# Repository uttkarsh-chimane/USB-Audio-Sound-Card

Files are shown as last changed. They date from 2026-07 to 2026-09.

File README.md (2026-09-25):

<h1 align="center">⚡ PCM2706 USB Audio Sound Card</h1>

<p align="center">
  
  
  
  
  
</p>

---

## ⚙️ What I Built

A compact USB-powered stereo audio sound card designed around the Texas Instruments PCM2706C USB Audio Codec. The device converts USB digital audio streams into analog stereo output and provides a simple plug-and-play audio interface for computers supporting the USB Audio Class standard.

---

## 🚀 Overview

This project implements a USB audio playback device using the PCM2706C USB audio codec. The design integrates USB communication, clock generation, analog audio filtering, and stereo output circuitry on a compact PCB developed in KiCad.

The board is powered directly from the USB port and outputs analog audio through a 3.5 mm audio jack.

---

## 📷 Project Gallery

🧩 **3D PCB Render**

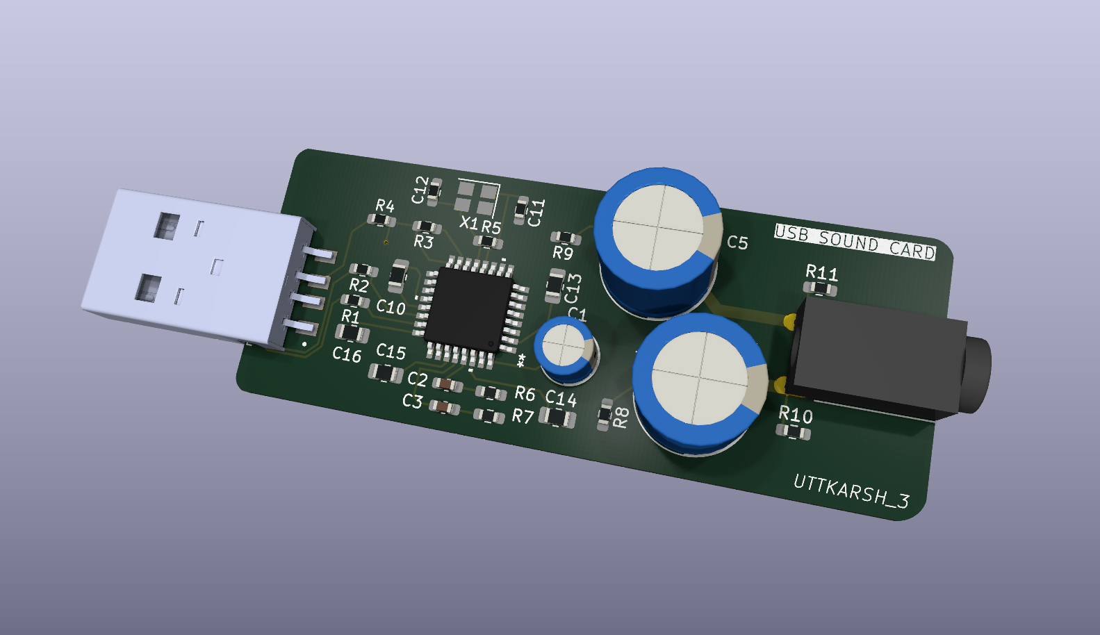
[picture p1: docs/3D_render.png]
3D PCB


🔌 **PCB Layout**

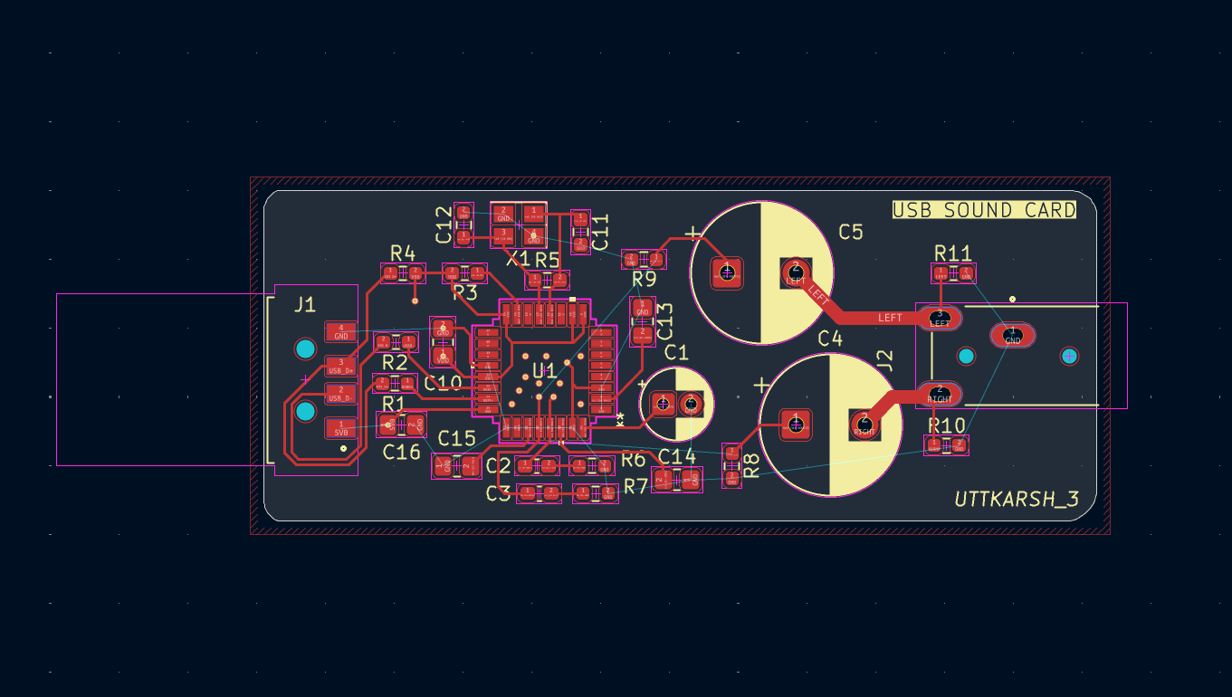
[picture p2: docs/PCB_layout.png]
PCB Layout


⚙️ **Schematic**

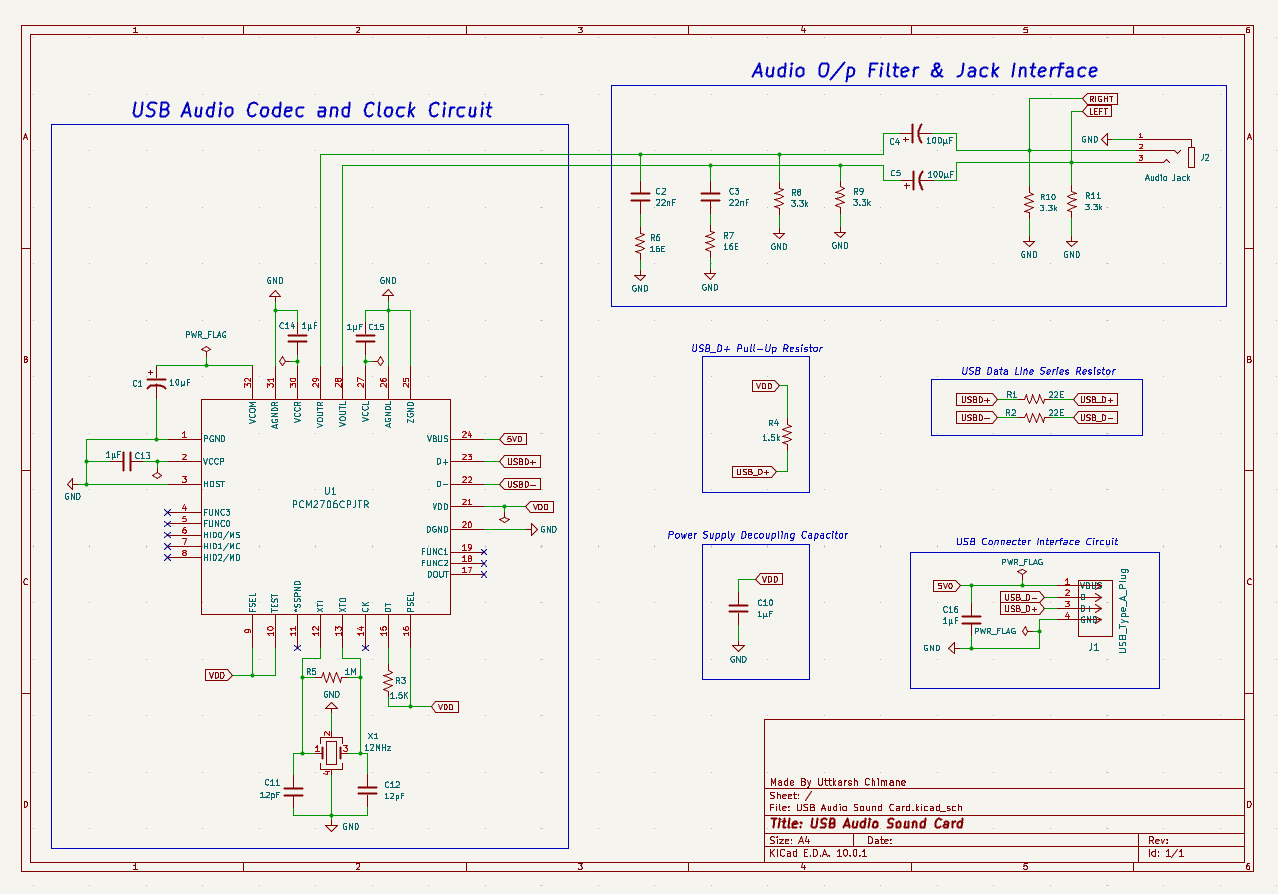
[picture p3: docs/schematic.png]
Schematic


---

## 📑 Component Reference Sheet

The complete component reference sheet is available here:

📄 [Reference.xlsx](docs/reference.xlsx)

The spreadsheet contains:
- Reference Designators
- Quantity
- Component Values
- Package Information
- Footprint Assignments
- Brief Component Descriptions

---

## ✨ Features

* USB Audio Class compliant architecture
* PCM2706C USB audio codec
* USB bus powered (5 V)
* Stereo analog audio output
* Integrated RC output filtering network
* 12 MHz crystal clock source
* Compact PCB footprint
* Designed using KiCad

---

## ⚒️ Hardware Architecture

```
USB Host
    │
    ▼
USB Connector
    │
    ▼
PCM2706C USB Audio Codec
    │
    ▼
RC Output Filter
    │
    ▼
3.5 mm Stereo Audio Jack
```
---

## 🧠 Schematic Highlights

**USB Interface**

* USB D+ and D− lines routed through 22 Ω series resistors.
* Pull-up resistor used for USB device detection.
* USB bus-powered operation.

**Clock Generation**

* 12 MHz crystal oscillator connected to the PCM2706C.
* Load capacitors selected according to crystal requirements.

**Audio Output Stage**

* Analog left and right channels filtered using RC networks.
* AC coupling capacitors remove DC offset before audio output.
* Stereo output available through a 3.5 mm audio jack.

**Power Integrity**

* Dedicated decoupling capacitors placed near codec supply pins.
* Separate analog and digital supply filtering considerations included.

---

## 🧩 PCB Design Insights

The PCB was designed as a compact single-board implementation with:

* Short USB signal paths
* Local decoupling near the codec IC
* Crystal placement close to oscillator pins
* Dedicated analog output filtering section
* 3D mechanical verification using external component models

---

## 🧪 Applications

* USB-to-analog audio conversion
* External USB sound card prototyping
* Educational projects involving USB Audio Class devices
* Audio codec evaluation and experimentation
* Mixed-signal PCB design learning
* Embedded audio hardware development

---

## ⚠️ Limitations

This project is intended for educational and design demonstration purposes.

* No integrated headphone amplifier stage
* Design has not been physically fabricated or tested
* Intended primarily for line-level audio output

---

## 🚀 Future Improvements

* USB-C connector variant
* Headphone amplifier stage
* ESD protection circuitry
* Improved analog output filtering
* Revision B PCB optimization

---

## 🛠️ Design Software

* KiCad 10
* Custom and vendor-provided symbol libraries
* Vendor STEP/IGES mechanical models

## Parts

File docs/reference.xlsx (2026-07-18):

# | Reference | Qty | Val | Package | Footprint | Brief Description
1 | C1 | 1 | CAP ALUM 10UF 20% 25V SMD | THT | CAP_UUQ_5X5P4_NCH / Capacitor_THT:CP_Radial_D5.0mm_P2.00mm | 10 ÂµF 25 V Aluminum Electrolytic Capacitors Radial, Can - SMD 1000 Hrs @ 105Â°C
2 | C2,C3 | 2 | CAP CER 0.022UF 50V X7R 0603 | 0603 (1608 Metric) | Capacitor_SMD:C_0603_1608Metric_Pad1.08x0.95mm_HandSolder | 0.022 ÂµF Â±10% 50V Ceramic Capacitor X7R 0603 (1608 Metric)
3 | C4,C5 | 2 | CAP ALUM 100UF 20% 50V RADIAL TH | THT | Capacitor_THT:CP_Radial_D10.0mm_P5.00mm | 100 ÂµF 50 V Aluminum Electrolytic Capacitors Radial, Can 3000 Hrs @ 105Â°C
4 | C10,C13,C14,C15,C16 | 5 | CAP CER 1UF 50V X7R 0805 | 0805 (2012 Metric) | Resistor_SMD:R_0805_2012Metric_Pad1.20x1.40mm_HandSolder | 1 ÂµF Â±10% 50V Ceramic Capacitor X7R 0805 (2012 Metric)
5 | C11,C12 | 2 | CAP CER 12PF 50V C0G 0603 | 0603 (1608 Metric) | Resistor_SMD:R_0603_1608Metric_Pad0.98x0.95mm_HandSolder | 12 pF Â±5% 50V Ceramic Capacitor C0G, NP0 0603 (1608 Metric)
6 | J1 | 1 | CONN PLUG USB2.0 TYPEA 4POS R/A | THT | 48037-1000:MOLEX_48037-1000 | USB-A (USB TYPE-A) USB 2.0 Plug Connector 4 Position Through Hole, Right Angle
7 | J2 | 1 | CONN JACK STEREO 3.5MM TH R/A | THT | STX-3000:KYCON_STX-3000 | 3.50mm (0.141", 1/8", Mini Plug) - Headphone Phone Jack Stereo (3 Conductor, TRS) Connector Kinked Pin
8 | R1,R2 | 2 | RES 22 OHM 1% 1/10W 0603 | 0603 (1608 Metric) | Resistor_SMD:R_0603_1608Metric_Pad0.98x0.95mm_HandSolder | 22 Ohms Â±1% 0.1W, 1/10W Chip Resistor 0603 (1608 Metric) Automotive AEC-Q200 Thick Film
9 | R3,R4 | 2 | RES SMD 1.5K OHM 1% 1/10W 0603 | 0603 (1608 Metric) | Resistor_SMD:R_0603_1608Metric_Pad0.98x0.95mm_HandSolder | 1.5 kOhms Â±1% 0.1W, 1/10W Chip Resistor 0603 (1608 Metric) Automotive AEC-Q200 Thick Film
10 | R5 | 1 | RES SMD 1M OHM 1% 1/10W 0603 | 0603 (1608 Metric) | Resistor_SMD:R_0603_1608Metric_Pad0.98x0.95mm_HandSolder | 1 MOhms Â±1% 0.1W, 1/10W Chip Resistor 0603 (1608 Metric) Automotive AEC-Q200 Thick Film
11 | R6,R7 | 2 | RES SMD 16 OHM 1% 1/10W 0603 | 0603 (1608 Metric) | Resistor_SMD:R_0603_1608Metric_Pad0.98x0.95mm_HandSolder | 16 Ohms Â±1% 0.1W, 1/10W Chip Resistor 0603 (1608 Metric) Automotive AEC-Q200 Thick Film
12 | R8,R9,R10,R11 | 4 | RES 3.3K OHM 1% 1/10W 0603 | 0603 (1608 Metric) | Resistor_SMD:R_0603_1608Metric_Pad0.98x0.95mm_HandSolder | 3.3 kOhms Â±1% 0.1W, 1/10W Chip Resistor 0603 (1608 Metric) Automotive AEC-Q200 Thick Film
13 | U1 | 1 | IC AUDIO SIGNAL PROCESSOR 32TQFP | 32-TQFP (7x7) | PCM2706CPJTR:STX-3000:KYCON_STX-3000 | Audio Audio Signal Processor 2 Channel 32-TQFP (7x7)
14 | X1 | 1 | CRYSTAL 12.0000MHZ 12PF SMD | 4-SMD | Crystal:Crystal_SMD_Abracon_ABM8AIG-4Pin_3.2x2.5mm | 12 MHz Â±20ppm Crystal 12pF 100 Ohms 4-SMD, No Lead

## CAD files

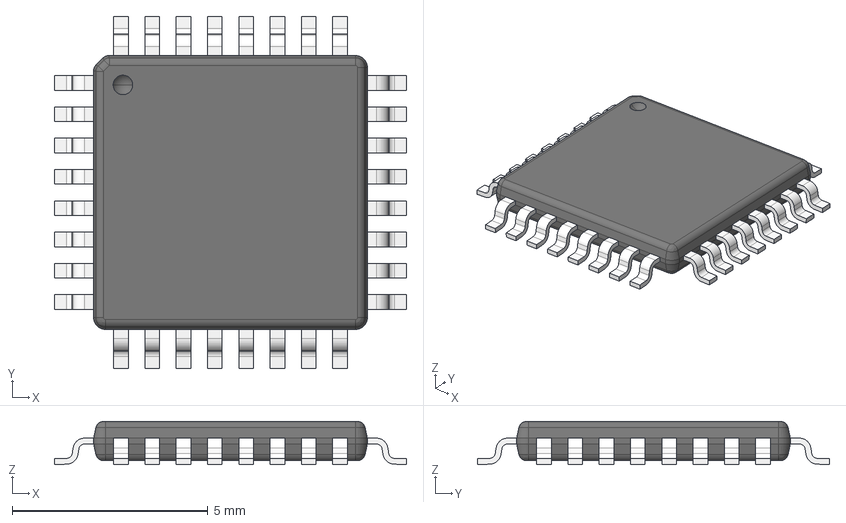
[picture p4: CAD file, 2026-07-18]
hardware/kiCad/3d_models/PJT0032A.stp
9.00 x 9.00 x 1.10 mm
LEAD-QFP x 32

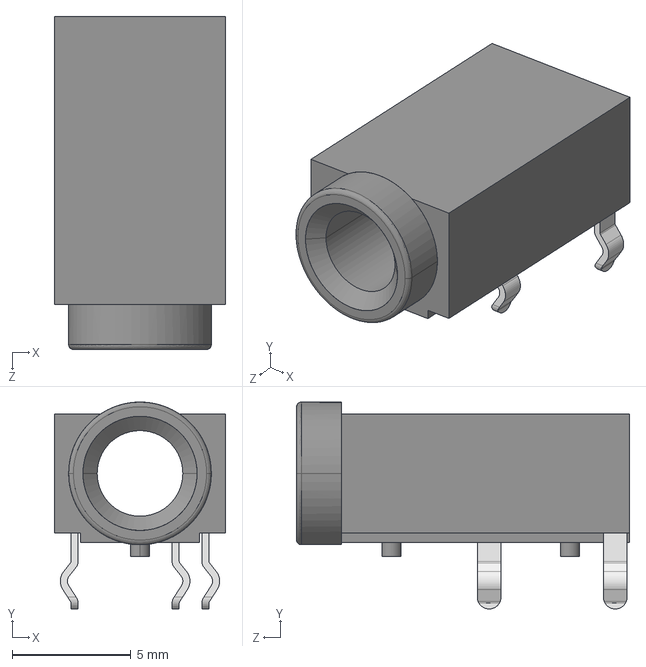
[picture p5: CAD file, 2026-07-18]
hardware/kiCad/3d_models/STX-3000_rD3.IGS
7.20 x 8.70 x 14.0 mm

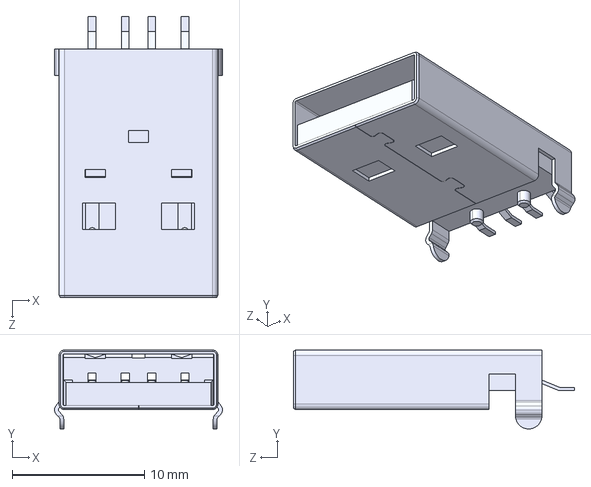
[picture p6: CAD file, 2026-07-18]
hardware/kiCad/3d_models/48037-1000--3DModel-STEP-56544.STEP
12.7 x 5.97 x 21.3 mm

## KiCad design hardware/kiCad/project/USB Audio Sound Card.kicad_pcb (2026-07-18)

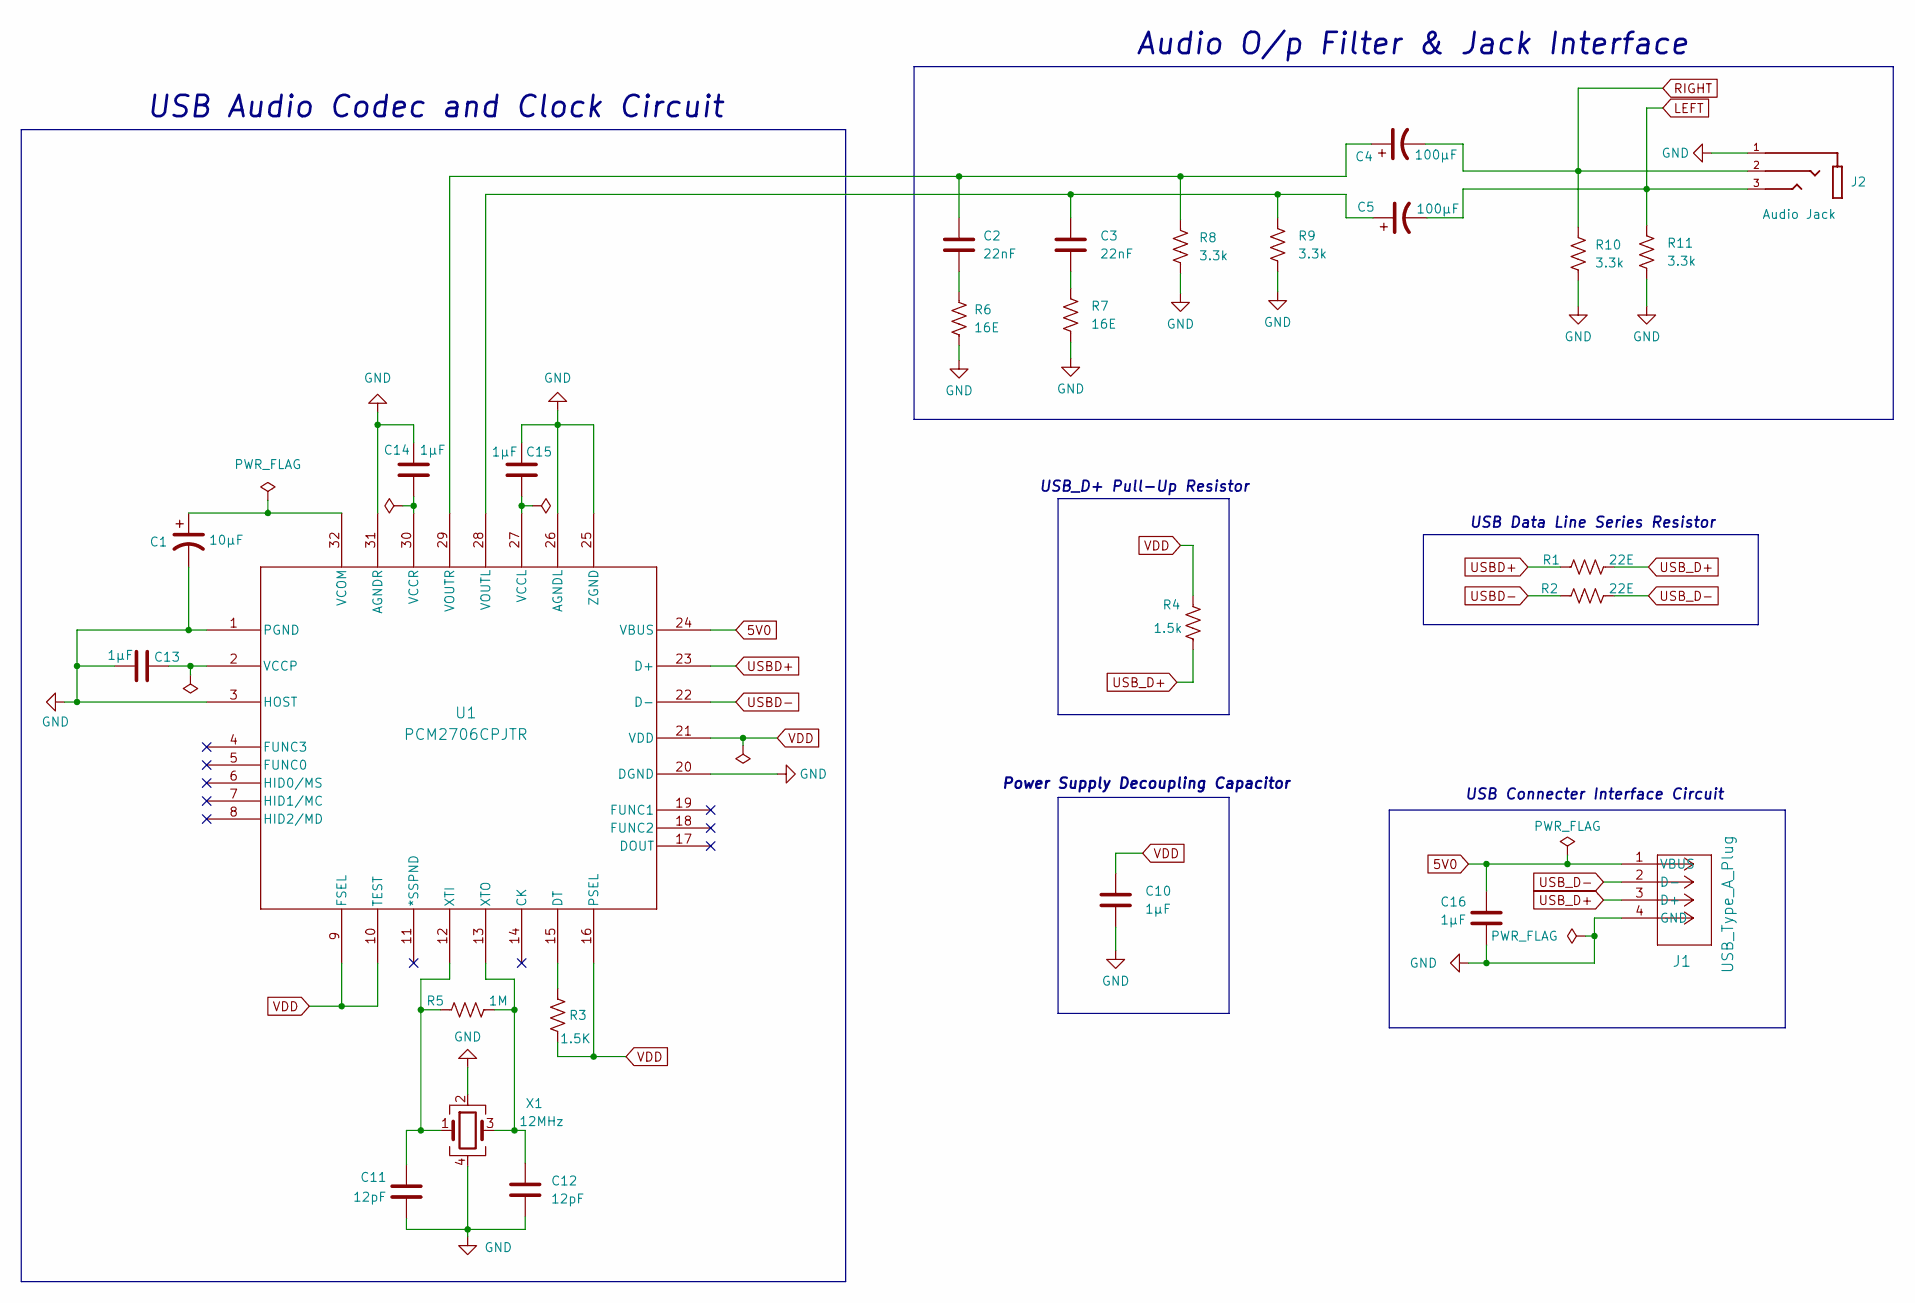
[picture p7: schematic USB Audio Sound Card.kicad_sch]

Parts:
C1: 10µF; CP_Radial_D5.0mm_P2.00mm
C2, C3: 22nF; C_0603_1608Metric_Pad1.08x0.95mm_HandSolder
C4, C5: 100µF; CP_Radial_D10.0mm_P5.00mm
C10, C13, C14, C15, C16: 1µF; R_0805_2012Metric_Pad1.20x1.40mm_HandSolder
C11, C12: 12pF; R_0603_1608Metric_Pad0.98x0.95mm_HandSolder
J1: USB_Type_A_Plug; MOLEX_48037-1000
J2: Audio Jack; KYCON_STX-3000; PARTREV D5; DigiKey_Part_Number 2092-STX-3000-ND
R1, R2: 22E; R_0603_1608Metric_Pad0.98x0.95mm_HandSolder
R3: 1.5K; R_0603_1608Metric_Pad0.98x0.95mm_HandSolder
R4: 1.5k; R_0603_1608Metric_Pad0.98x0.95mm_HandSolder
R5: 1M; R_0603_1608Metric_Pad0.98x0.95mm_HandSolder
R6, R7: 16E; R_0603_1608Metric_Pad0.98x0.95mm_HandSolder
R8, R9, R10, R11: 3.3k; R_0603_1608Metric_Pad0.98x0.95mm_HandSolder
U1: PCM2706CPJTR; PJT32
X1: 12MHz; Crystal_SMD_Abracon_ABM8AIG-4Pin_3.2x2.5mm

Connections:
5V0: C16.1, J1.1 (VBUS), U1.24 (VBUS)
GND: C1.2, C10.2, C11.2, C12.2, C13.1, C14.1, C15.1, C16.2, J1.4 (GND), J2.1, R6.2, R7.2, R8.2, R9.2, R10.2, R11.2, U1.1 (PGND), U1.3 (HOST), U1.20 (DGND), U1.25 (ZGND), U1.26 (AGNDL), U1.31 (AGNDR), X1.2, X1.4
LEFT: C5.2, J2.3, R11.1
unnamed: C2.2, R6.1
unnamed: C3.2, R7.1
unnamed: R3.1, U1.15 (DT)
unnamed: C15.2, U1.27 (VCCL)
unnamed: C13.2, U1.2 (VCCP)
unnamed: C14.2, U1.30 (VCCR)
unnamed: C1.1, U1.32 (VCOM)
unnamed: C3.1, C5.1, R9.1, U1.28 (VOUTL)
unnamed: C2.1, C4.1, R8.1, U1.29 (VOUTR)
unnamed: C11.1, R5.2, U1.12 (XTI), X1.1
unnamed: C12.1, R5.1, U1.13 (XTO), X1.3
RIGHT: C4.2, J2.2, R10.1
USBD+: R1.1, U1.23 (D+)
USBD-: R2.1, U1.22 (D-)
USB_D+: J1.3 (D+), R1.2, R4.1
USB_D-: J1.2 (D-), R2.2
VDD: C10.1, R3.2, R4.2, U1.9 (FSEL), U1.10 (TEST), U1.16 (PSEL), U1.21 (VDD)

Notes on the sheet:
USB_D+ Pull-Up Resistor
USB Audio Codec and Clock Circuit
USB Data Line Series Resistor
USB Connecter Interface Circuit
Power Supply Decoupling Capacitor
Audio O/p Filter & Jack Interface

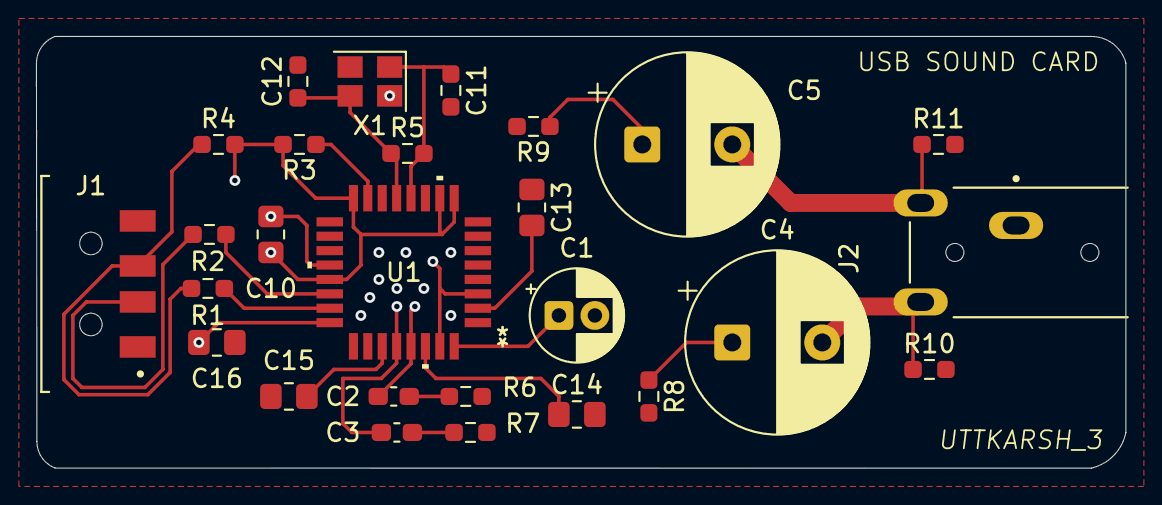
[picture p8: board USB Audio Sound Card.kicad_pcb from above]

Board: 2 copper layers, 60.5 x 24.0 mm, 27 parts (0 on the bottom side), 20 nets.
